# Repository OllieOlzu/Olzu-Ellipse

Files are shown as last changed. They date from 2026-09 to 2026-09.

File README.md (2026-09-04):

# Olzu-Ellipse
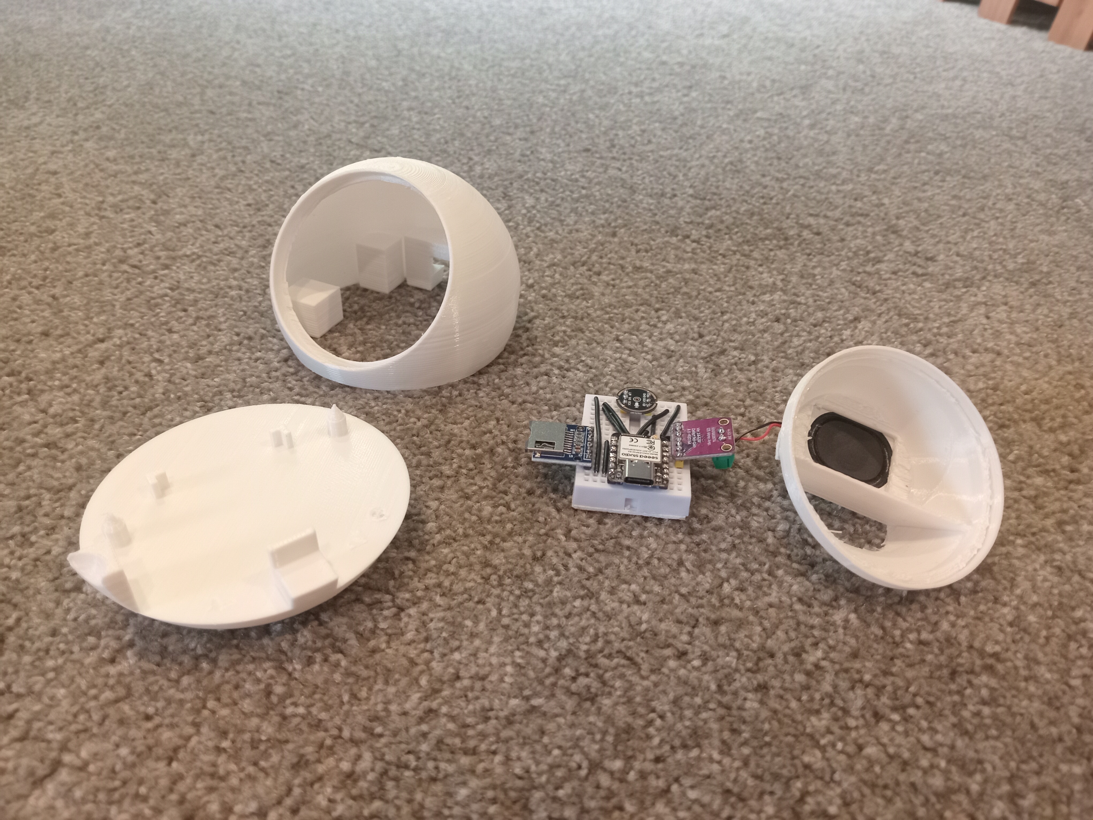
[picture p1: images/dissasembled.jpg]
Main image

My project for an awesome voice controlled music player! 

---

Welcome.

TL;DR, over the past few months, I have been developing this project, intending to sell it somewhere, but isn't good enough to sell, so here it is open source.

# How to make:

### Parts list:

| Part | Where to buy | Cost (USD) |
|---|---|---:|
| XIAO ESP32S3 | Seeed studios | $11 |
| INMP441 microphone | Aliexpress | $1 |
| MAX98357A amplifyer | Aliexpress | $1 |
| SD card module | Aliexpress | $2 |
| Mini breadboard SBY-170 | Aliexpress | $1 |
| 8 Ohm speaker 3525/2535 slot | Aliexpress | $2 |
| 22AWG PVC wire | Aliexpress | $2 |

First thing, get ESP-IDF V5.2.7, as that is what works with the ESP-IDF ADE and Speech recog. I used the VS code exntention. Next, download and open the project in PlatformIO. 

Next, wire up the bread board like this:

```
// INMP441 microphone -- I2S0, RX 
#define MIC_WS_IO     GPIO_NUM_2    // D1
#define MIC_SCK_IO    GPIO_NUM_3    // D2
#define MIC_SD_IO     GPIO_NUM_4    // D3
 
// MAX98357A amplifier -- I2S1, TX (separate I2S peripheral from the mic)
#define SPK_BCLK_IO   GPIO_NUM_6    // D5
#define SPK_WS_IO     GPIO_NUM_5    // D4
#define SPK_DOUT_IO   GPIO_NUM_43   // D6 (UART0 console disabled)
 
// MicroSD card -- SPI bus
#define SD_SCK_IO     GPIO_NUM_7    // D8
#define SD_MISO_IO    GPIO_NUM_44   // D7 (UART0 console disabled)
#define SD_MOSI_IO    GPIO_NUM_8    // D9
#define SD_CS_IO      GPIO_NUM_9    // D10
```
Just wires:

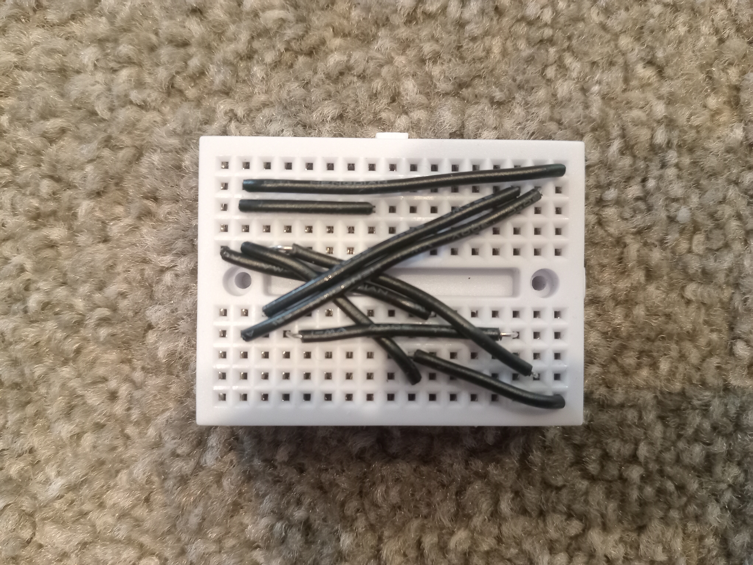
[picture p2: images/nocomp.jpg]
Main image


With components:

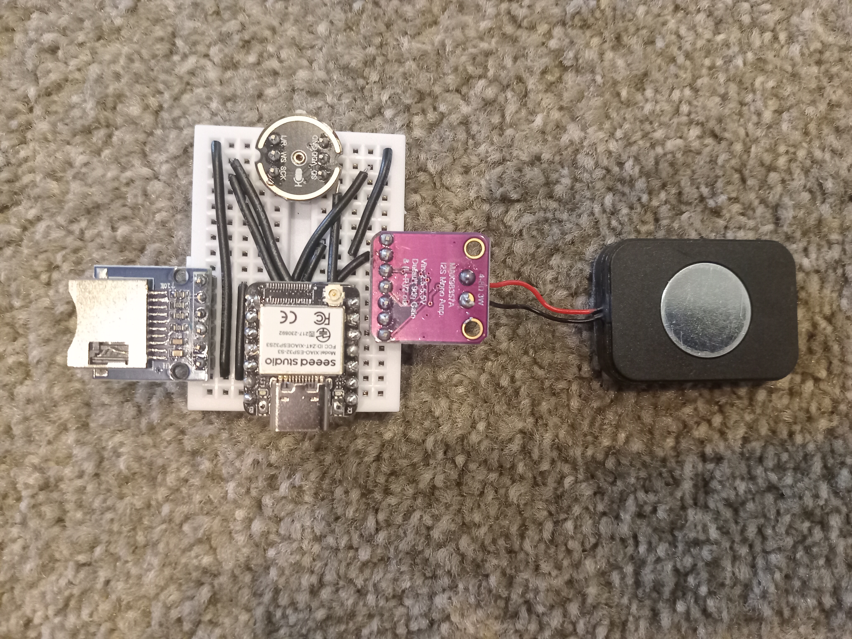
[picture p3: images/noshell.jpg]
Main image


Then, 3DP the parts. Draw seams on the indents of the male and female base and shell prongs.

Assemble, upload code, then put your songs on in the form of MP4 or WAV (WAV may sometimes skip songs) with 1.mp3, 2.wav, 3.mp3, etc with that order of titles dictating play order. Then, ask "Ellipse," then play, stop, next, back, volume up, or volume down. It should act like this:

[Video](https://drive.google.com/file/d/1HiCZSoKqFnZCQKwasglbz2WqJZx6tAWT)

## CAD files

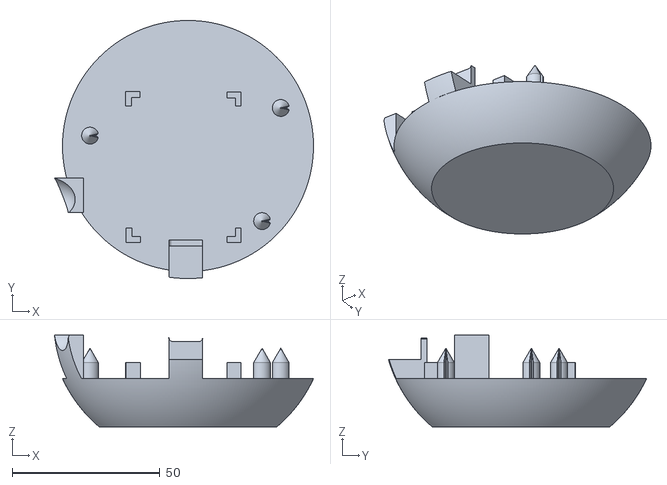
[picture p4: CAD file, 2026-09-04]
3dpparts/base.stl
87.6 x 87.2 x 31.0

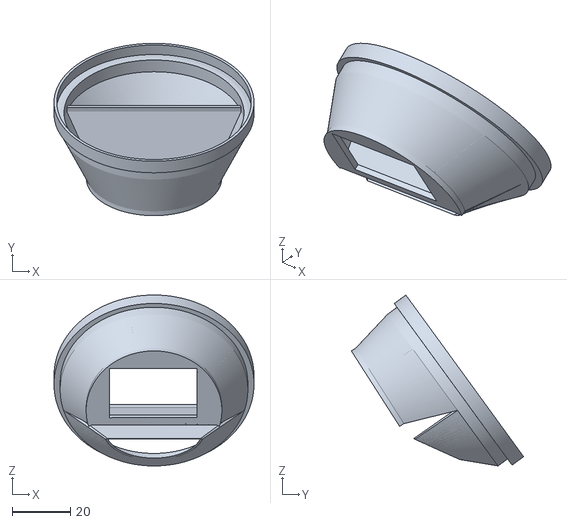
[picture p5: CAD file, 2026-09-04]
3dpparts/reverb.stl
68.5 x 59.0 x 58.5

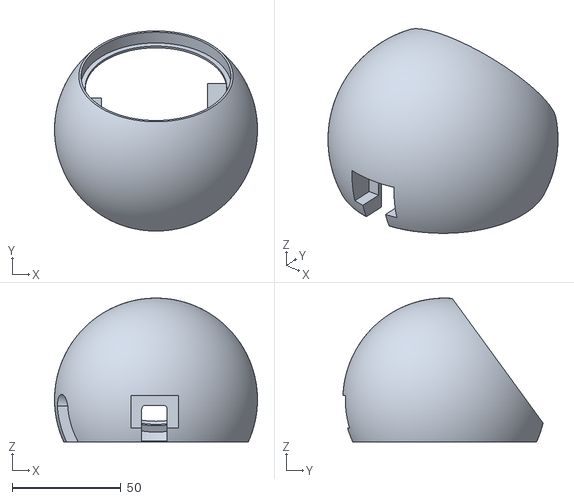
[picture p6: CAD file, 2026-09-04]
3dpparts/shell.stl
93.3 x 92.0 x 66.1

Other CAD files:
3dpparts/Project.blend

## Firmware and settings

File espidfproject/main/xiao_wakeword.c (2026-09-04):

/* =============================================================================
 * Voice-Controlled SD Card Music Player
 * -----------------------------------------------------------------------------
 * Target hardware : Seeed XIAO ESP32S3
 *                    INMP441   I2S microphone   (I2S0, RX)
 *                    MAX98357A I2S class-D amp  (I2S1, TX)
 *                    MicroSD card module        (SPI)
 *                    Onboard yellow LED          GPIO21, active-low
 *                    External LED strip          GPIO1 (D0), PWM-faded
 * Framework        : ESP-IDF v5.x, ESP-ADF (audio_pipeline), ESP-SR (MultiNet, English)
 *
 * Voice model
 * -----------
 * A single ESP-SR MultiNet (English) instance recognizes every phrase below
 * — no WakeNet model is loaded. Three wake-word phrases (WAKE_WORD_1/2/3
 * below, default "HEY SPEAKER" / "WAKE UP" / "COMPUTER") are treated as
 * equivalent by an application-level state machine in voice_task(): hearing
 * any one of them opens a command-listening window.
 *
 *   wake word    -> hearing any of WAKE_WORD_1/2/3 turns the onboard LED on,
 *                   fades the D0 strip LED in over LED_FADE_TIME, ducks the
 *                   music down to LISTENING_VOLUME so it's still just
 *                   audible in the background, and opens a command window
 *                   (LISTEN_WINDOW_US, currently 7 s).
 *   PLAY         -> resume the current track from where it left off
 *   STOP         -> pause; remembers the exact position, then feeds the amp
 *                   STOP_SILENCE_MS of real silence (see note below)
 *   BACK         -> jump to the previous track (by sorted position, not by
 *                   literal file number — see track-list notes below) and
 *                   play it from the start
 *   NEXT         -> jump to the next track and play it from the start
 *   RESTART      -> jump to the lowest-numbered track and play it from the start
 *   VOLUME DOWN  -> volume -= VOLUME_CHANGE
 *   VOLUME UP    -> volume += VOLUME_CHANGE
 *
 * Whichever of the above is recognized (or if the window simply times out
 * with nothing recognized), the music is restored to whatever volume it was
 * at *before* the wake word — then, if a real command came in, that command
 * is applied on top of the restored volume. So "VOLUME UP" raises the
 * volume you were already listening at, not LISTENING_VOLUME.
 *
 * Both LEDs turn off the instant a valid command is recognized, or when the
 * window expires, whichever happens first — the onboard LED switches off
 * immediately, the D0 strip LED fades out over LED_FADE_TIME. Detection
 * never blocks (no vTaskDelay in the recognition loop), so a wake word and
 * a command can be spoken with very little gap between them.
 *
 * MAX98357A silence handling
 * ---------------------------
 * The I2S TX peripheral repeats whatever was in its last DMA buffer(s) once
 * it runs out of freshly-written audio, rather than going quiet — the
 * MAX98357A just faithfully plays whatever it's handed. Real silence is
 * therefore written into the TX ring explicitly at the moments new audio is
 * about to stop flowing — see i2s_write_silence_ms() and its call sites in
 * player_open_track() and the CMD_STOP handler.
 *
 * Track numbering and supported formats
 * ---------------------------------------
 * Tracks are named "<number>.wav" or "<number>.mp3" on the SD card (1.mp3,
 * 2.wav, 3.mp3, ...) — the two formats can be freely mixed. Numbers may skip
 * (e.g. 1.mp3, 3.wav, 8.mp3 exist but 2,4-7 don't). At boot, the SD card
 * root directory is scanned once and every valid "<number>.wav"/"<number>.mp3"
 * file is recorded into a sorted list. NEXT/BACK/RESTART all operate on
 * *positions in that sorted list*, not on the literal file numbers, so gaps
 * are handled automatically: NEXT always goes to the next highest number
 * that actually exists, BACK to the next lowest, RESTART to the lowest one
 * present, and all three wrap around at the ends of the list.
 *
 * Playback goes through an ESP-ADF audio_pipeline:
 *
 *     [fatfs reader] -> [mp3_decoder or wav_decoder] -> [rsp_filter] -> [raw_stream]
 *
 * "rsp_filter" resamples and, if needed, downmixes whatever the decoder
 * reports for the current file — any sample rate, mono or stereo — down to
 * a fixed 44.1 kHz mono stream (PLAYBACK_SAMPLE_RATE below), which is what
 * raw_stream hands back to playback_task one chunk at a time via
 * raw_stream_read(). playback_task then applies volume and writes the
 * result straight to the MAX98357A with i2s_channel_write(). Source files
 * don't need to be pre-converted to any particular rate, bit depth or
 * channel count — an MP3 or WAV ripped straight from anywhere can just be
 * dropped on the card.
 *
 * Only the decoder element differs between an MP3 and a WAV track; the
 * reader, resample filter and raw sink are created once at boot and stay
 * put for the life of the program. When the next track needs the other
 * decoder, player_open_track() swaps it in with
 * audio_pipeline_breakup_elements()/audio_pipeline_relink().
 *
 * main/CMakeLists.txt's PRIV_REQUIRES needs audio_pipeline, audio_stream,
 * mp3_decoder, wav_decoder, rsp_filter, audio_sal and fatfs (or just
 * "esp-adf-libs" if your ESP-ADF checkout bundles the individual codec
 * components into that single component instead).
 *
 * The microphone path (INMP441 -> MultiNet) runs at 16 kHz, which is what
 * ESP-SR's MultiNet expects and is unrelated to the 44.1 kHz playback path
 * described above.
 *
 * Required one-time project configuration:
 *   idf.py menuconfig -> Component config -> ESP System Settings ->
 *     Channel for console output -> "USB Serial JTAG Controller"
 * This frees GPIO43/44 (D6/D7) from the default UART0 console assignment —
 * D6 carries the amplifier's DOUT line and D7 carries the SD card's MISO
 * line, both used below. Flashing and monitoring continue to work over the
 * same USB-C port.
 *
 * ESP-ADF's audio_stream component always pulls in a board definition
 * (components/audio_board), even though this file never calls into it — the
 * mic and speaker I2S channels are driven entirely by hand below, so
 * ESP-ADF never touches that hardware directly. The stock default
 * (Audio HAL -> Audio board -> "ESP32-Lyrat V4.3" in menuconfig) is fine to
 * leave selected; its pin values are simply never used by anything here.
 * ========================================================================== */

#include <stdio.h>
#include <string.h>
#include <strings.h>
#include <stdlib.h>
#include <stdint.h>
#include <assert.h>
#include <dirent.h>

#include "freertos/FreeRTOS.h"
#include "freertos/task.h"
#include "freertos/queue.h"

#include "driver/i2s_std.h"
#include "driver/gpio.h"
#include "driver/ledc.h"
#include "driver/spi_master.h"
#include "driver/sdspi_host.h"
#include "sdmmc_cmd.h"
#include "esp_vfs_fat.h"

#include "esp_log.h"
#include "esp_timer.h"
#include "esp_err.h"

#include "model_path.h"
#include "esp_mn_iface.h"
#include "esp_mn_models.h"
#include "esp_mn_speech_commands.h"

/* ESP-ADF: audio_pipeline/audio_element core, plus the specific elements the
 * playback pipeline described above is built from. */
#include "audio_element.h"
#include "audio_pipeline.h"
#include "audio_event_iface.h"
#include "fatfs_stream.h"
#include "raw_stream.h"
#include "mp3_decoder.h"
#include "wav_decoder.h"
#include "filter_resample.h"

static const char *TAG = "voice_player";

/* -----------------------------------------------------------------------
 *  Pin map — Seeed XIAO ESP32S3
 *  D-number / GPIO pairs confirmed against Seeed's official pinout table.
 *  All 11 header pins (D0-D10) are used.
 * ----------------------------------------------------------------------- */

// INMP441 microphone -- I2S0, RX
#define MIC_WS_IO     GPIO_NUM_2    // D1
#define MIC_SCK_IO    GPIO_NUM_3    // D2
#define MIC_SD_IO     GPIO_NUM_4    // D3

// MAX98357A amplifier -- I2S1, TX (separate I2S peripheral from the mic)
#define SPK_BCLK_IO   GPIO_NUM_6    // D5
#define SPK_WS_IO     GPIO_NUM_5    // D4
#define SPK_DOUT_IO   GPIO_NUM_43   // D6 (requires UART0 console disabled, see header notes)

// MicroSD card -- SPI bus
#define SD_SCK_IO     GPIO_NUM_7    // D8
#define SD_MISO_IO    GPIO_NUM_44   // D7 (requires UART0 console disabled, see header notes)
#define SD_MOSI_IO    GPIO_NUM_8    // D9
#define SD_CS_IO      GPIO_NUM_9    // D10

// Onboard user LED (yellow), active-low
#define LED_GPIO      GPIO_NUM_21

// External LED strip (standard on/off strip, not addressable), PWM-faded
#define STRIP_LED_GPIO GPIO_NUM_1    // D0

#define SD_MOUNT_POINT "/sdcard"
#define SD_SPI_HOST    SPI2_HOST

/* -----------------------------------------------------------------------
 *  Wake words -- any one of the three opens a command-listening window.
 *  Edit these freely; MultiNet matches English phrases directly, no
 *  additional model training is needed.
 * ----------------------------------------------------------------------- */
#define WAKE_WORD_1   "ELIPS"
#define WAKE_WORD_2   "AHLIPS"
#define WAKE_WORD_3   "ILLIPS"

/* -----------------------------------------------------------------------
 *  Voice command IDs registered with MultiNet
 * ----------------------------------------------------------------------- */
#define CMD_WAKE1_ID      1
#define CMD_WAKE2_ID      2
#define CMD_WAKE3_ID      3
#define CMD_PLAY_ID       4
#define CMD_STOP_ID       5
#define CMD_BACK_ID       6
#define CMD_NEXT_ID       7
#define CMD_RESTART_ID    8
#define CMD_VOL_DOWN_ID   9
#define CMD_VOL_UP_ID     10

#define LISTEN_WINDOW_US       (7 * 1000 * 1000)  // 7 s LED "listening" window -- gives
                                                   // "VOLUME UP"/"VOLUME DOWN" a comfortable
                                                   // margin to be spoken in full without timing out.
#define MN_CREATE_DURATION_MS  7000                // MultiNet's own internal backstop timer,
                                                    // matched to LISTEN_WINDOW_US above.

/* -----------------------------------------------------------------------
 *  Player tunables
 * ----------------------------------------------------------------------- */
static const float VOLUME_CHANGE = 0.1f;   // step size for "VOLUME UP" / "VOLUME DOWN"

#define INITIAL_VOLUME      0.3f
#define MIN_VOLUME          0.0f
#define MAX_VOLUME          1.0f
#define CLIP_MIN            (-12000)
#define CLIP_MAX            (12000)

// Volume the player ducks to while listening for a command after the wake
// word, so the music stays just barely audible instead of competing with
// the mic for the user's command. Restored once a command is heard or the
// listening window times out -- see CMD_DUCK_VOLUME / CMD_RESTORE_VOLUME.
#define LISTENING_VOLUME    0.05f

// How long to feed the MAX98357A real silence for when STOP is heard,
// instead of just halting playback -- see i2s_write_silence_ms().
#define STOP_SILENCE_MS      250

// Silence flushed into the TX ring right before opening a different track
// (BACK/NEXT/RESTART/first PLAY), so nothing left over from the previous
// track is sitting there for the peripheral to loop on during the restart.
#define TRACK_SWITCH_FLUSH_MS 100

#define AUDIO_CHUNK_BYTES     4096   // ~46 ms of audio @ 44.1 kHz/16-bit/mono per loop iteration
#define MAX_TRACKS            200

// rsp_filter resamples/downmixes every track to this rate; i2s_speaker_init()
// below clocks the I2S peripheral to match.
#define PLAYBACK_SAMPLE_RATE  44100

// playback_task and every ESP-ADF pipeline element task run on this core;
// voice_task (mic capture + MultiNet inference) runs on the other one, so
// playback and voice recognition never compete for CPU time on the same core.
#define PLAYBACK_CORE  1
#define VOICE_CORE     0

/* -----------------------------------------------------------------------
 *  External LED strip -- PWM fade via the LEDC hardware peripheral. Fades
 *  are driven by hardware/ISR once started, so they never block voice_task
 *  or playback_task.
 * ----------------------------------------------------------------------- */
#define STRIP_LED_PWM_TIMER      LEDC_TIMER_0
#define STRIP_LED_PWM_CHANNEL    LEDC_CHANNEL_0
#define STRIP_LED_PWM_MODE       LEDC_LOW_SPEED_MODE
#define STRIP_LED_PWM_RES        LEDC_TIMER_10_BIT        // duty range 0-1023
#define STRIP_LED_PWM_FREQ_HZ    5000
#define STRIP_LED_PWM_MAX_DUTY   ((1 << STRIP_LED_PWM_RES) - 1)

#define LED_FADE_TIME            500   // ms -- fade in/out duration for the strip LED

typedef enum {
    CMD_NONE = 0,
    CMD_PLAY,
    CMD_STOP,
    CMD_BACK,
    CMD_NEXT,
    CMD_RESTART,
    CMD_VOL_UP,
    CMD_VOL_DOWN,
    CMD_DUCK_VOLUME,     // entered the post-wake-word listening window
    CMD_RESTORE_VOLUME,  // listening window ended (command heard, or timed out)
} player_cmd_t;

static QueueHandle_t s_cmd_queue;
static i2s_chan_handle_t s_rx_handle = NULL;   // microphone
static i2s_chan_handle_t s_tx_handle = NULL;   // speaker

/* ============================== Track list ============================== */

typedef enum { TRACK_EXT_WAV, TRACK_EXT_MP3 } track_ext_t;

typedef struct {
    int        number;   // the "<number>" part of the filename
    track_ext_t ext;
} track_entry_t;

typedef struct {
    track_entry_t entries[MAX_TRACKS];
    int count;
} track_list_t;

static track_list_t s_tracks = { .count = 0 };

static int track_entry_cmp(const void *a, const void *b) {
    return ((const track_entry_t *)a)->number - ((const track_entry_t *)b)->number;
}

// Fills *number/*ext and returns true if `name` matches exactly
// "<digits>.wav" or "<digits>.mp3" (case-insensitive extension); returns
// false otherwise. Rejects anything with trailing junk after the extension
// or no digits at all.
static bool parse_track_filename(const char *name, int *number, track_ext_t *ext) {
    int i = 0;
    long value = 0;
    int digits = 0;
    while (name[i] >= '0' && name[i] <= '9') {
        if (digits >= 9) return false;  // implausibly long number, not a real track
        value = value * 10 + (name[i] - '0');
        i++;
        digits++;
    }
    if (digits == 0) return false;
    if (strcasecmp(&name[i], ".wav") == 0) {
        *number = (int)value;
        *ext = TRACK_EXT_WAV;
        return true;
    }
    if (strcasecmp(&name[i], ".mp3") == 0) {
        *number = (int)value;
        *ext = TRACK_EXT_MP3;
        return true;
    }
    return false;
}

static void scan_tracks(void) {
    s_tracks.count = 0;
    DIR *dir = opendir(SD_MOUNT_POINT);
    if (!dir) {
        ESP_LOGE(TAG, "Could not open %s to scan for tracks", SD_MOUNT_POINT);
        return;
    }
    struct dirent *entry;
    while ((entry = readdir(dir)) != NULL) {
        int number;
        track_ext_t ext;
        if (parse_track_filename(entry->d_name, &number, &ext) && s_tracks.count < MAX_TRACKS) {
            s_tracks.entries[s_tracks.count].number = number;
            s_tracks.entries[s_tracks.count].ext = ext;
            s_tracks.count++;
        }
    }
    closedir(dir);
    qsort(s_tracks.entries, s_tracks.count, sizeof(track_entry_t), track_entry_cmp);

    if (s_tracks.count == 0) {
        ESP_LOGW(TAG, "No '<number>.wav' or '<number>.mp3' files found on SD card");
    } else {
        ESP_LOGI(TAG, "Found %d track(s) on SD card:", s_tracks.count);
        for (int i = 0; i < s_tracks.count; i++) {
            ESP_LOGI(TAG, "  position %d -> %d.%s", i, s_tracks.entries[i].number,
                     s_tracks.entries[i].ext == TRACK_EXT_MP3 ? "mp3" : "wav");
        }
    }
}

// Position in the sorted list, wrapping. These are what BACK/NEXT use, so
// gaps in numbering (1, 3, 8 ...) are followed correctly in both directions.
static int next_index(int index) { return (index + 1) % s_tracks.count; }
static int prev_index(int index) { return (index - 1 + s_tracks.count) % s_tracks.count; }

/* ====================== Player state (owned by playback_task only) ====================== */
// Everything below is touched exclusively from playback_task. Commands
// arrive only via the queue, so there is no shared-state race and no mutex
// is needed anywhere in this file.

typedef struct {
    int   track_index;    // position in s_tracks.entries[]
    bool  track_loaded;   // true once the pipeline has been successfully primed for track_index
    bool  playing;
    float volume;
    bool  ducked;         // true while volume == LISTENING_VOLUME (see CMD_DUCK_VOLUME)
    float saved_volume;   // volume to restore to once CMD_RESTORE_VOLUME arrives
} player_state_t;

static player_state_t s_player = {
    .track_index = 0,
    .track_loaded = false,
    .playing = false,
    .volume = INITIAL_VOLUME,
    .ducked = false,
    .saved_volume = INITIAL_VOLUME,
};

static void track_path(int index, char *buf, size_t buf_len) {
    const track_entry_t *t = &s_tracks.entries[index];
    snprintf(buf, buf_len, "%s/%d.%s", SD_MOUNT_POINT, t->number, t->ext == TRACK_EXT_MP3 ? "mp3" : "wav");
}

// Writes `ms` milliseconds of silence to the speaker. The I2S TX peripheral
// repeats whatever was in its last DMA buffer once it runs out of freshly-
// written audio instead of going quiet, so silence is written explicitly
// here at track transitions and on STOP to prevent audible looping.
static void i2s_write_silence_ms(uint32_t ms) {
    static const uint8_t silence[256] = {0}; // 16-bit samples -> always write an even byte count
    size_t total_bytes = (size_t)(((uint64_t)PLAYBACK_SAMPLE_RATE * 2 * ms) / 1000);
    size_t done = 0;
    while (done < total_bytes) {
        size_t want = total_bytes - done;
        if (want > sizeof(silence)) want = sizeof(silence);
        size_t written = 0;
        esp_err_t err = i2s_channel_write(s_tx_handle, silence, want, &written, portMAX_DELAY);
        if (err != ESP_OK) {
            ESP_LOGE(TAG, "Speaker write failed (%s) -- check amplifier wiring "
                          "(BCLK/WS/DOUT to D5/D4/D6)", esp_err_to_name(err));
            break; // don't spin forever if the driver reports trouble
        }
        if (written == 0) break;
        done += written;
    }
}

/* ============================== ESP-ADF playback pipeline ==============================
 *
 *   [fatfs reader] -> [mp3_decoder or wav_decoder] -> [rsp_filter] -> [raw_stream]
 *
 * playback_task pulls decoded/resampled/downmixed 16-bit mono PCM out of the
 * raw_stream end with raw_stream_read() and writes it to the speaker,
 * applying volume and the silence-flush workaround above in playback_task
 * itself. Only the decoder element linked into the pipeline changes between
 * tracks (see player_open_track()); the reader, filter and sink are created
 * once here and stay put.
 */
static audio_pipeline_handle_t    s_pipeline;
static audio_event_iface_handle_t s_pipeline_evt;
static audio_element_handle_t     s_fatfs_el;
static audio_element_handle_t     s_mp3_el;
static audio_element_handle_t     s_wav_el;
static audio_element_handle_t     s_rsp_el;
static audio_element_handle_t     s_raw_el;
static track_ext_t                s_active_ext;   // which decoder is currently linked into the pipeline
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
void app_main(void) {
    led_init();
    strip_led_init();

    if (sd_card_init() != ESP_OK) {
        ESP_LOGE(TAG, "Continuing without a usable SD card -- voice commands "
                      "will be recognized, but playback will have no tracks to play "
                      "until the card is fixed and the board is reset.");
    }
    scan_tracks();

    i2s_mic_init();
    i2s_speaker_init();
    player_pipeline_init();

    s_cmd_queue = xQueueCreate(8, sizeof(player_cmd_t));
    assert(s_cmd_queue);

    // Pinned to separate cores -- see PLAYBACK_CORE/VOICE_CORE above.
    xTaskCreatePinnedToCore(playback_task, "playback", 6144, NULL, 5, NULL, PLAYBACK_CORE);
    xTaskCreatePinnedToCore(voice_task,    "voice",    8192, NULL, 5, NULL, VOICE_CORE);
}

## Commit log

2026-09-04 Enhance README with project details and setup guide
    Added detailed project description, parts list, and assembly instructions.
2026-09-04 Revise README with parts list and assembly steps
    Updated parts list and instructions for assembly.
